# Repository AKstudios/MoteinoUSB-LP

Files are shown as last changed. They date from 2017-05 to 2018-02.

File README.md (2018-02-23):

# MoteinoUSB-LP
Moteino USB (R5) with a unidirectional voltage level shifter (TI [SN74LVC1T45](http://www.ti.com/lit/ds/symlink/sn74lvc1t45.pdf)) to isolate current sources. This prevents parasitic current draw through FTDI's RX pin when USB is unplugged and lowers overall sleep current draw to almost the same as a base Moteino without FTDI. Measured current draw with voltage level shifter: ~6.6uA.

Alternative design using an N-channel MOSFET for voltage level shifting also included. This is cheaper than using the level shifter and lowers the current draw to ~6.4uA.

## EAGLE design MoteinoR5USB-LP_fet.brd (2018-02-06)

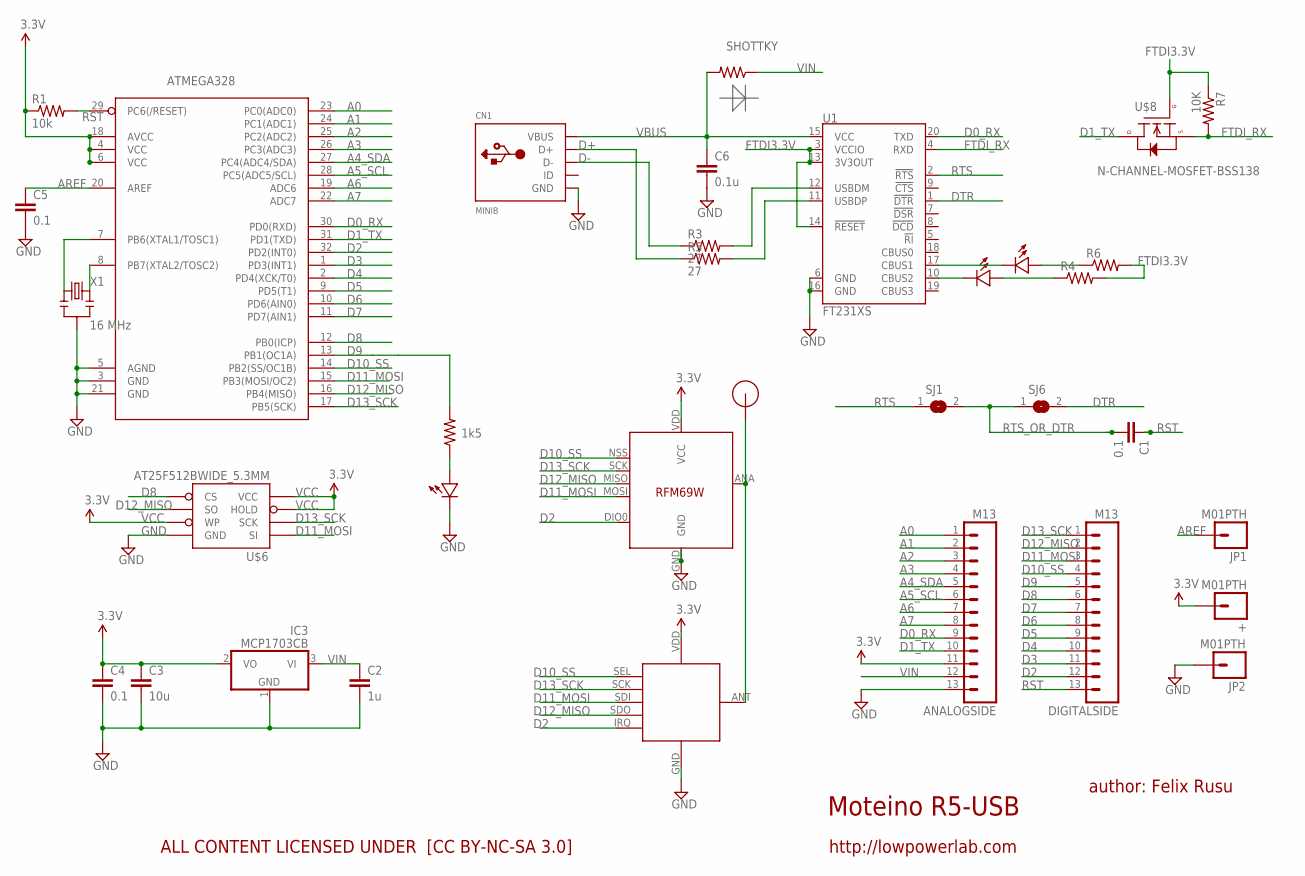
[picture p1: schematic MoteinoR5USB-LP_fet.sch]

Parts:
+: M01PTH; 1X01
ANALOGSIDE: M13; 1X13
ATMEGA328: ATMega-328; TQFP32-08
C1, C4, C5: 0.1; 0603-CAP
C2: 1u; 0603-CAP
C3: 10u; 0805-CAP
C6: 0.1u; 0603-CAP
CN1: MINIB; USB-MINIB
D: SHOTTKY; 0603-RES
DIGITALSIDE: M13; 1X13
IC3: MCP1703CB; SOT23
JP1, JP2: M01PTH; 1X01
R1: 10k; 0603-RES
R2: 1k5; 0603-RES
R3, R5: 27; 0603-RES
R4, R6: RESISTOR0603-RES; 0603-RES
R7: 10K; R0805
RFM12B: RFM12B_MINPADS; RFM12B-MINPADS
SJ1, SJ6: JUMPER; SJW
U1: FT231XS; SSOP20_L
U$1: RFM12B_ANTENNA; RFM12B-ANTENNA
U$2, U$4, U$7: LED0603; 0603-LED
U$5: RFM69; RFM69W-MINPADS
U$6: AT25F512BWIDE_5.3MM; SO08WIDE
U$8: N-CHANNEL-MOSFET-BSS138; SOT23-3
X1: 16 MHz; RESONATOR-SMD

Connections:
A0: ANALOGSIDE.1, ATMEGA328.23 (PC0(ADC0))
A1: ANALOGSIDE.2, ATMEGA328.24 (PC1(ADC1))
A2: ANALOGSIDE.3, ATMEGA328.25 (PC2(ADC2))
A3: ANALOGSIDE.4, ATMEGA328.26 (PC3(ADC3))
A4_SDA: ANALOGSIDE.5, ATMEGA328.27 (PC4(ADC4/SDA))
A5_SCL: ANALOGSIDE.6, ATMEGA328.28 (PC5(ADC5/SCL))
A6: ANALOGSIDE.7, ATMEGA328.19 (ADC6)
A7: ANALOGSIDE.8, ATMEGA328.22 (ADC7)
AREF: ATMEGA328.20 (AREF), C5.1, JP1.1
D0_RX: ANALOGSIDE.9, ATMEGA328.30 (PD0(RXD)), U1.20 (TXD)
D1_TX: ANALOGSIDE.10, ATMEGA328.31 (PD1(TXD)), U$8.3 (D)
D2: ATMEGA328.32 (PD2(INT0)), DIGITALSIDE.12, RFM12B.IRQ, U$5.DIO0
D3: ATMEGA328.1 (PD3(INT1)), DIGITALSIDE.11
D4: ATMEGA328.2 (PD4(XCK/T0)), DIGITALSIDE.10
D5: ATMEGA328.9 (PD5(T1)), DIGITALSIDE.9
D6: ATMEGA328.10 (PD6(AIN0)), DIGITALSIDE.8
D7: ATMEGA328.11 (PD7(AIN1)), DIGITALSIDE.7
D8: ATMEGA328.12 (PB0(ICP)), DIGITALSIDE.6, U$6.1 (CS)
D9: ATMEGA328.13 (PB1(OC1A)), DIGITALSIDE.5, R2.2
D10_SS: ATMEGA328.14 (PB2(SS/OC1B)), DIGITALSIDE.4, RFM12B.SEL, U$5.NSS (SEL)
D11_MOSI: ATMEGA328.15 (PB3(MOSI/OC2)), DIGITALSIDE.3, RFM12B.SDI (SDI/MOSI), U$5.MOSI, U$6.5 (SI)
D12_MISO: ATMEGA328.16 (PB4(MISO)), DIGITALSIDE.2, RFM12B.SDO (SDO/MISO), U$5.MISO, U$6.2 (SO)
D13_SCK: ATMEGA328.17 (PB5(SCK)), DIGITALSIDE.1, RFM12B.SCK, U$5.SCK, U$6.6 (SCK)
D+: CN1.D+, R5.1
D-: CN1.D-, R3.1
DTR: SJ6.2, U1.1 (!DTR)
FTDI3.3V: R4.2, R6.2, R7.1, U1.3 (VCCIO), U1.13 (3V3OUT), U1.14 (!RESET), U$8.1 (G)
FTDI_RX: R7.2, U1.4 (RXD), U$8.2 (S)
GND: ANALOGSIDE.13, ATMEGA328.3 (GND), ATMEGA328.5 (AGND), ATMEGA328.21 (GND), C2.2, C3.2, C4.2, C5.2, C6.2, CN1.GND, IC3.1 (GND), JP2.1, RFM12B.GND, U1.6 (GND), U1.16 (GND), U$2.MINUS, U$5.GND, U$6.4 (GND), X1.2
unnamed: ATMEGA328.7 (PB6(XTAL1/TOSC1)), X1.1
unnamed: R2.1, U$2.PLUS
unnamed: RFM12B.ANT, U$1.P$1, U$5.ANA (ANT)
unnamed: R3.2, U1.12 (USBDM)
unnamed: R5.2, U1.11 (USBDP)
unnamed: U1.17 (CBUS1), U$4.MINUS
unnamed: U1.10 (CBUS2), U$7.MINUS
unnamed: R4.1, U$7.PLUS
unnamed: R6.1, U$4.PLUS
unnamed: ATMEGA328.8 (PB7(XTAL2/TOSC2)), X1.3
RST: ATMEGA328.29 (PC6(/RESET)), C1.1, DIGITALSIDE.13, R1.2
RTS: SJ1.1, U1.2 (!RTS)
RTS_OR_DTR: C1.2, SJ1.2, SJ6.1
VBUS: C6.1, CN1.VBUS, D.2, U1.15 (VCC)
VCC: +.1, ANALOGSIDE.11, ATMEGA328.4 (VCC), ATMEGA328.6 (VCC), ATMEGA328.18 (AVCC), C3.1, C4.1, IC3.2 (VO), R1.1, RFM12B.VDD, U$5.VDD (VCC), U$6.3 (WP), U$6.7 (HOLD), U$6.8 (VCC)
VIN: ANALOGSIDE.12, C2.1, D.1, IC3.3 (VI)

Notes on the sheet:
Moteino R5-USB
author: Felix Rusu
http://lowpowerlab.com
ALL CONTENT LICENSED UNDER [CC BY-NC-SA 3.0]

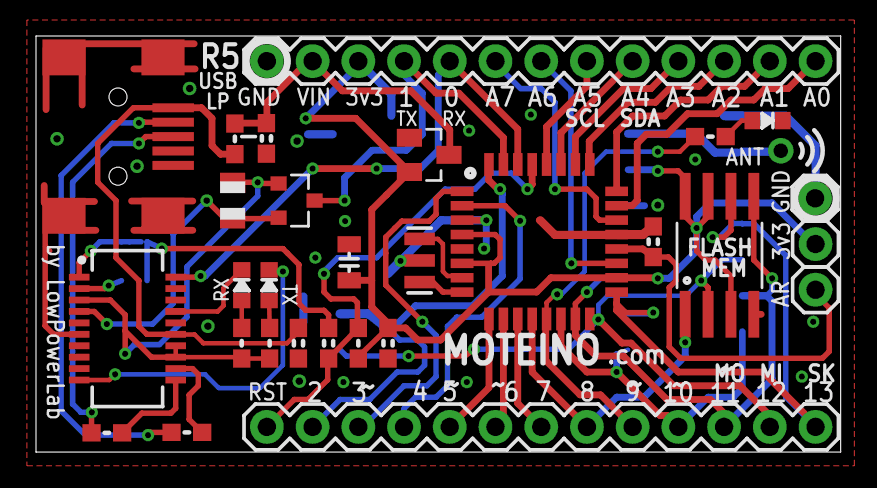
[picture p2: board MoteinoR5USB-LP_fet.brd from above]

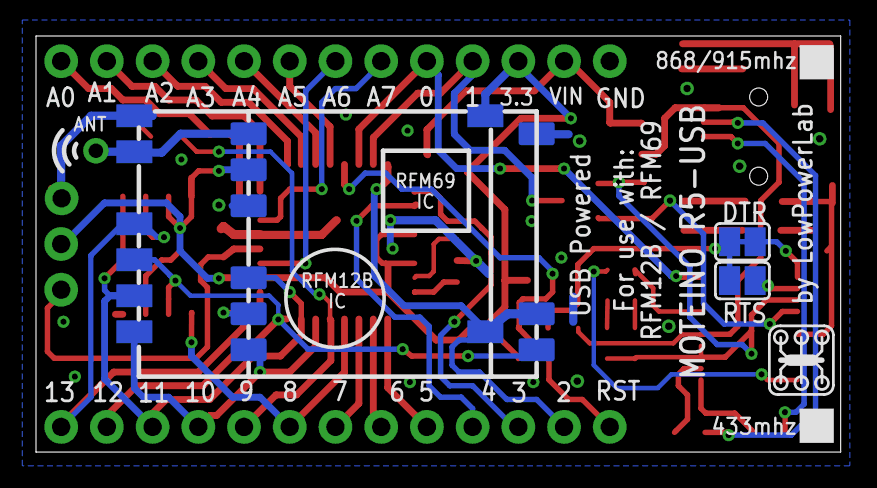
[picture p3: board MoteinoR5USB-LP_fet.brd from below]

Board: 2 copper layers, 44.7 x 23.1 mm, 35 parts (5 on the bottom side), 45 nets.

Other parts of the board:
U$3: LOGO_LOWPOWERLAB

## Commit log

2017-05-12 Uploaded EAGLE files
    [MoteinoR6USB.brd, MoteinoR6USB.sch]
2018-02-06 Added a MOSFET variant
    - replaced voltage shifter with mosfet
    - some trace & silkscreen adjustments on both boards
    [MoteinoR5USB-LP.brd, MoteinoR5USB-LP.sch, MoteinoR5USB-LP_fet.brd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]

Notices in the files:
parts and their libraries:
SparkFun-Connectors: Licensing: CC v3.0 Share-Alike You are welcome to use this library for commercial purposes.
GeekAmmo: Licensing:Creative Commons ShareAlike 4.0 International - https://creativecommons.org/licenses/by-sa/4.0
